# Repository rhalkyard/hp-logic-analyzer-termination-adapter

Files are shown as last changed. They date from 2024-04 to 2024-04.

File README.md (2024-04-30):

# Termination Adapter for HP Logic Analyzers

The PCB in this repo is a quick and dirty clone of the HP 01650-63203
termination adapter, used for direct connection of a 40-pin pod cable to a
dedicated test port, providing a passive termination network to minimise loading
on the device under test. By adding a cheap set of hookup leads and
minigrabbers, it can also serve as a DIY replacement for the probe pods that are
so frequently missing from analzyers that crop up on the used market.

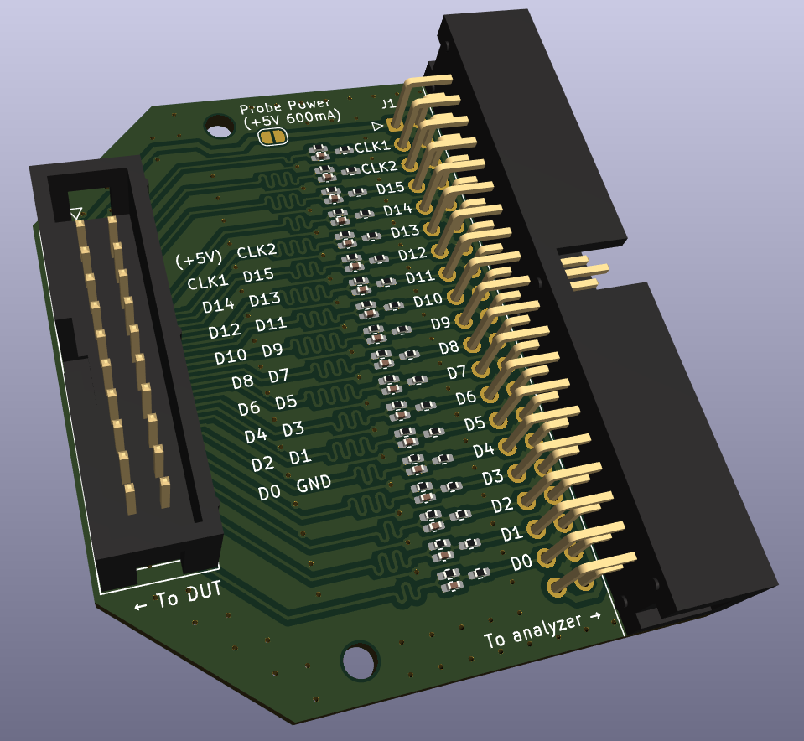
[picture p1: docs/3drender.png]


## Termination network

Per HP application note [AP1244 "Minimizing Intrusion Effects when Probing with
a Logic Analyzer"](docs/5962-8620E_AP1244-1_Minimizing_Intrusion_Effects_When_Probing_With_a_Logic_Analyzer_Jul95),
each probe must be terminated with a series RC network as below (from Figure 1):

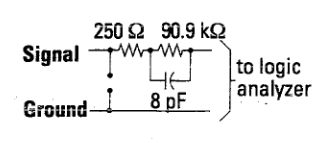
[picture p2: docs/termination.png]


HP sold arrays of this termination network (1810-1278 for 9 networks in a DIP
package, 1810-1588 for 5 networks in a SIP package). Naturally these are either
NLA or not available for purchase by mere mortals, but it's easy enough to
implement it in discrete components.

## Pinouts

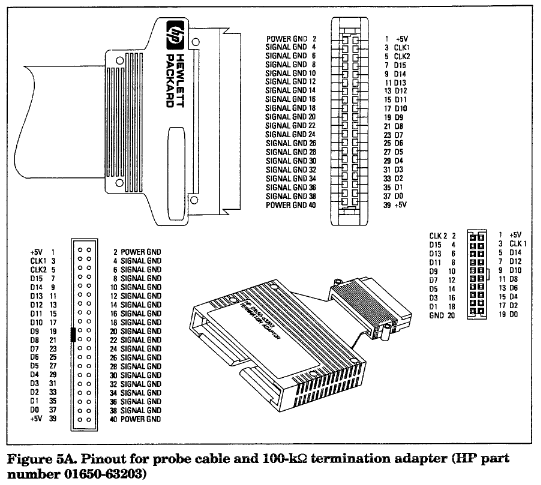
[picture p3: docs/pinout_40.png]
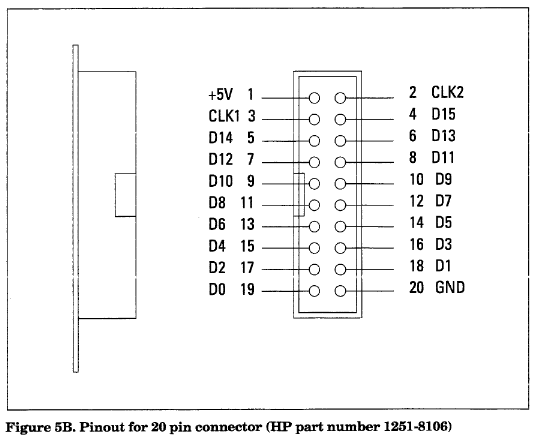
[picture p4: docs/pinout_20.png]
 

## Power

The logic analyzer supplies +5V at 600mA to each pod connector on pins 1 and 39
of the 40-pin connector. The 01650-63203 termination adatper brings this supply
out to pin 1 of the 20-pin connector. Per HP's documentation, this is intended
solely for powering active probe hardware, and must be a no-connect on the
device under test.

For safety, on this adapter, the +5V supply is broken by a solder jumper that
must be closed in order to supply +5V to the 20 pin connector.

## BOM and assembly

Each adapter requires the following

| Quantity | Component |
|---|---|
| 18 | Capacitor, 8pF, 0402 footprint |
| 18 | Resistor, 250 ohm 1%, 0402 footprint |
| 18 | Resistor, 90.9K 1%, 0402 footprint |
| 1 | Keyed 0.1" PCB header, 2x20 pin, right angle |
| 1 | Keyed 0.1" PCB header, 2x10 pin, vertical |
| 1 (optional) | 20 pin IDC ribbon cable, length to taste, female connectors |

Conveniently, JLCPCB's minimum order quantity of 5 is exactly the number of pods
required for my 1652B analyzer. I ordered a set of 5 boards with SMD components
preassembled for approximately 25 USD.

The original 01650-63203 adapters had an exposed section of flexible PCB,
terminated in a 20 pin IDC receptacle, designed to directly connect to a
board-mounted header on the DUT. This adapter substitutes this with a header - a
short length of ribbon cable can be used to connect to the DUT, or standard
Dupont leads can be connected to the pins for individual probes.

## (Lack of) Warranty

This project is presented on an as-is, 'works for me' basis. You are welcome to
build it, use it, adapt it to your own purposes, but all at your own risk.

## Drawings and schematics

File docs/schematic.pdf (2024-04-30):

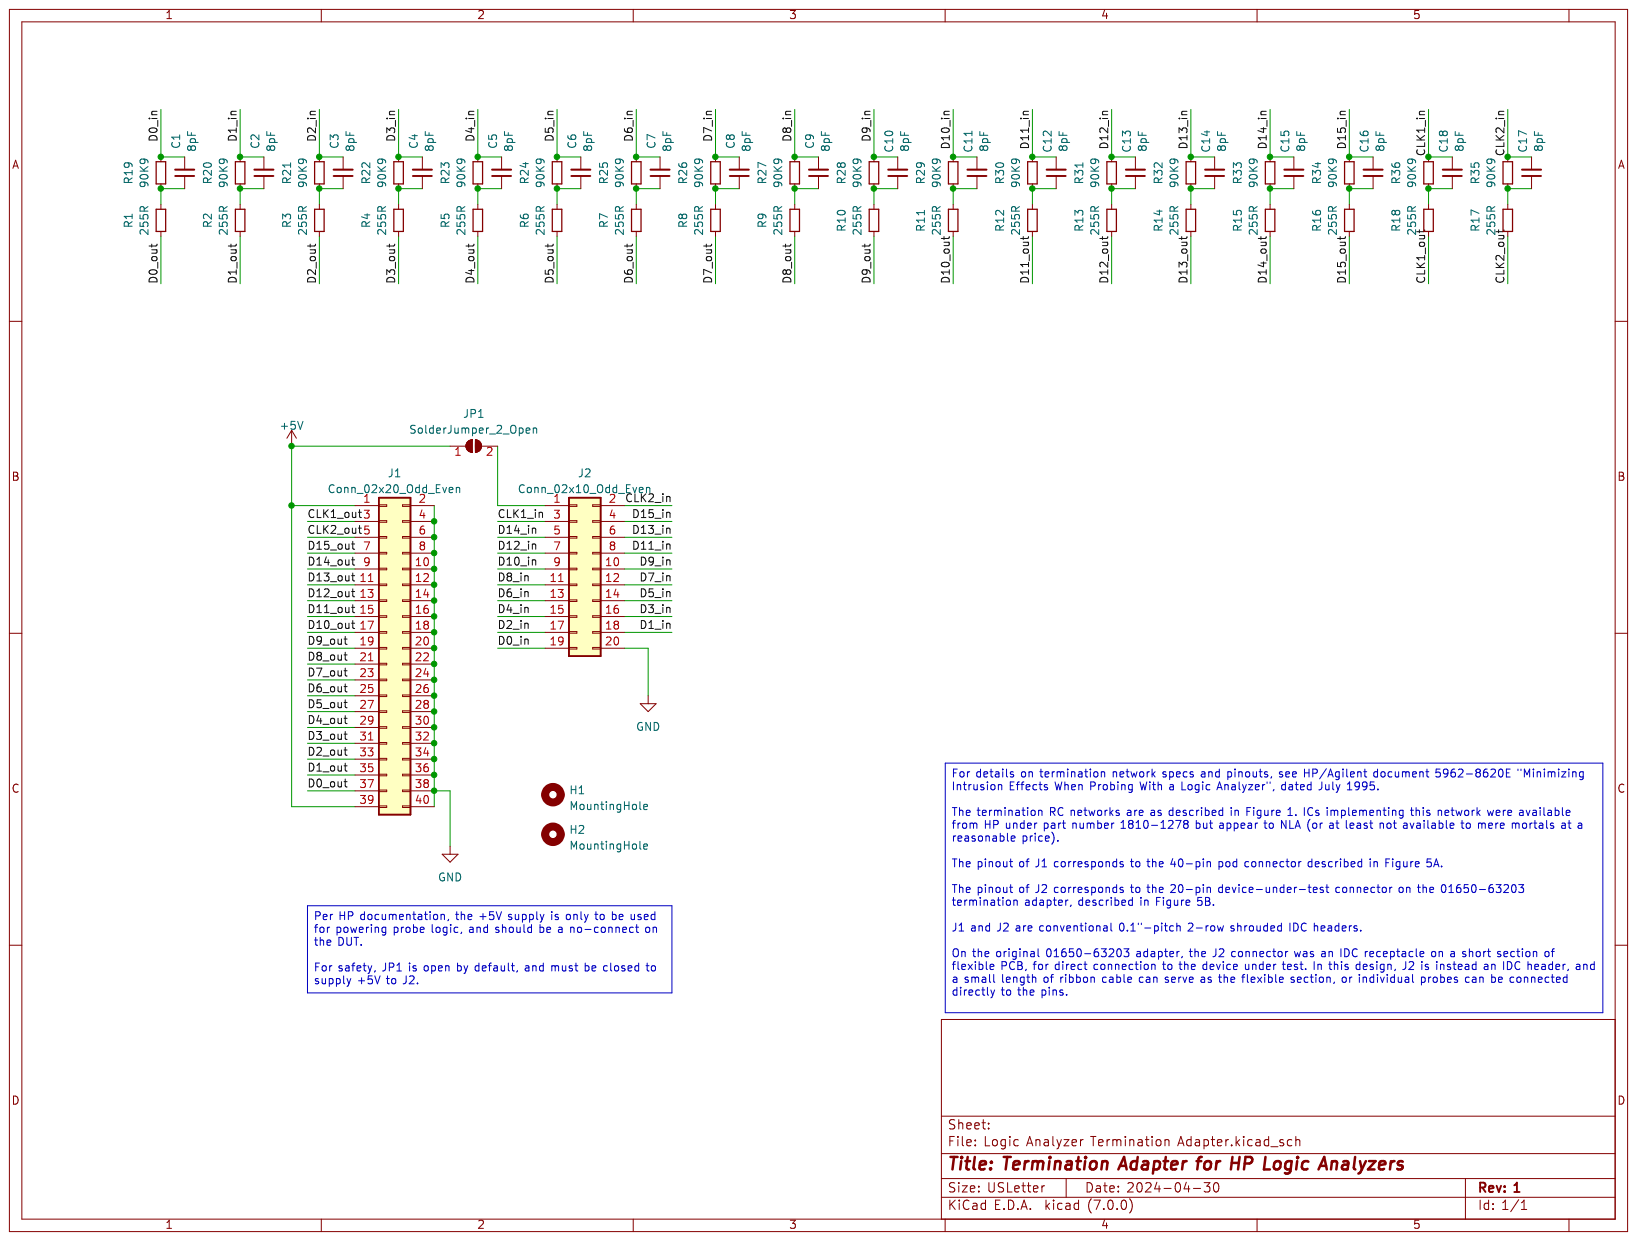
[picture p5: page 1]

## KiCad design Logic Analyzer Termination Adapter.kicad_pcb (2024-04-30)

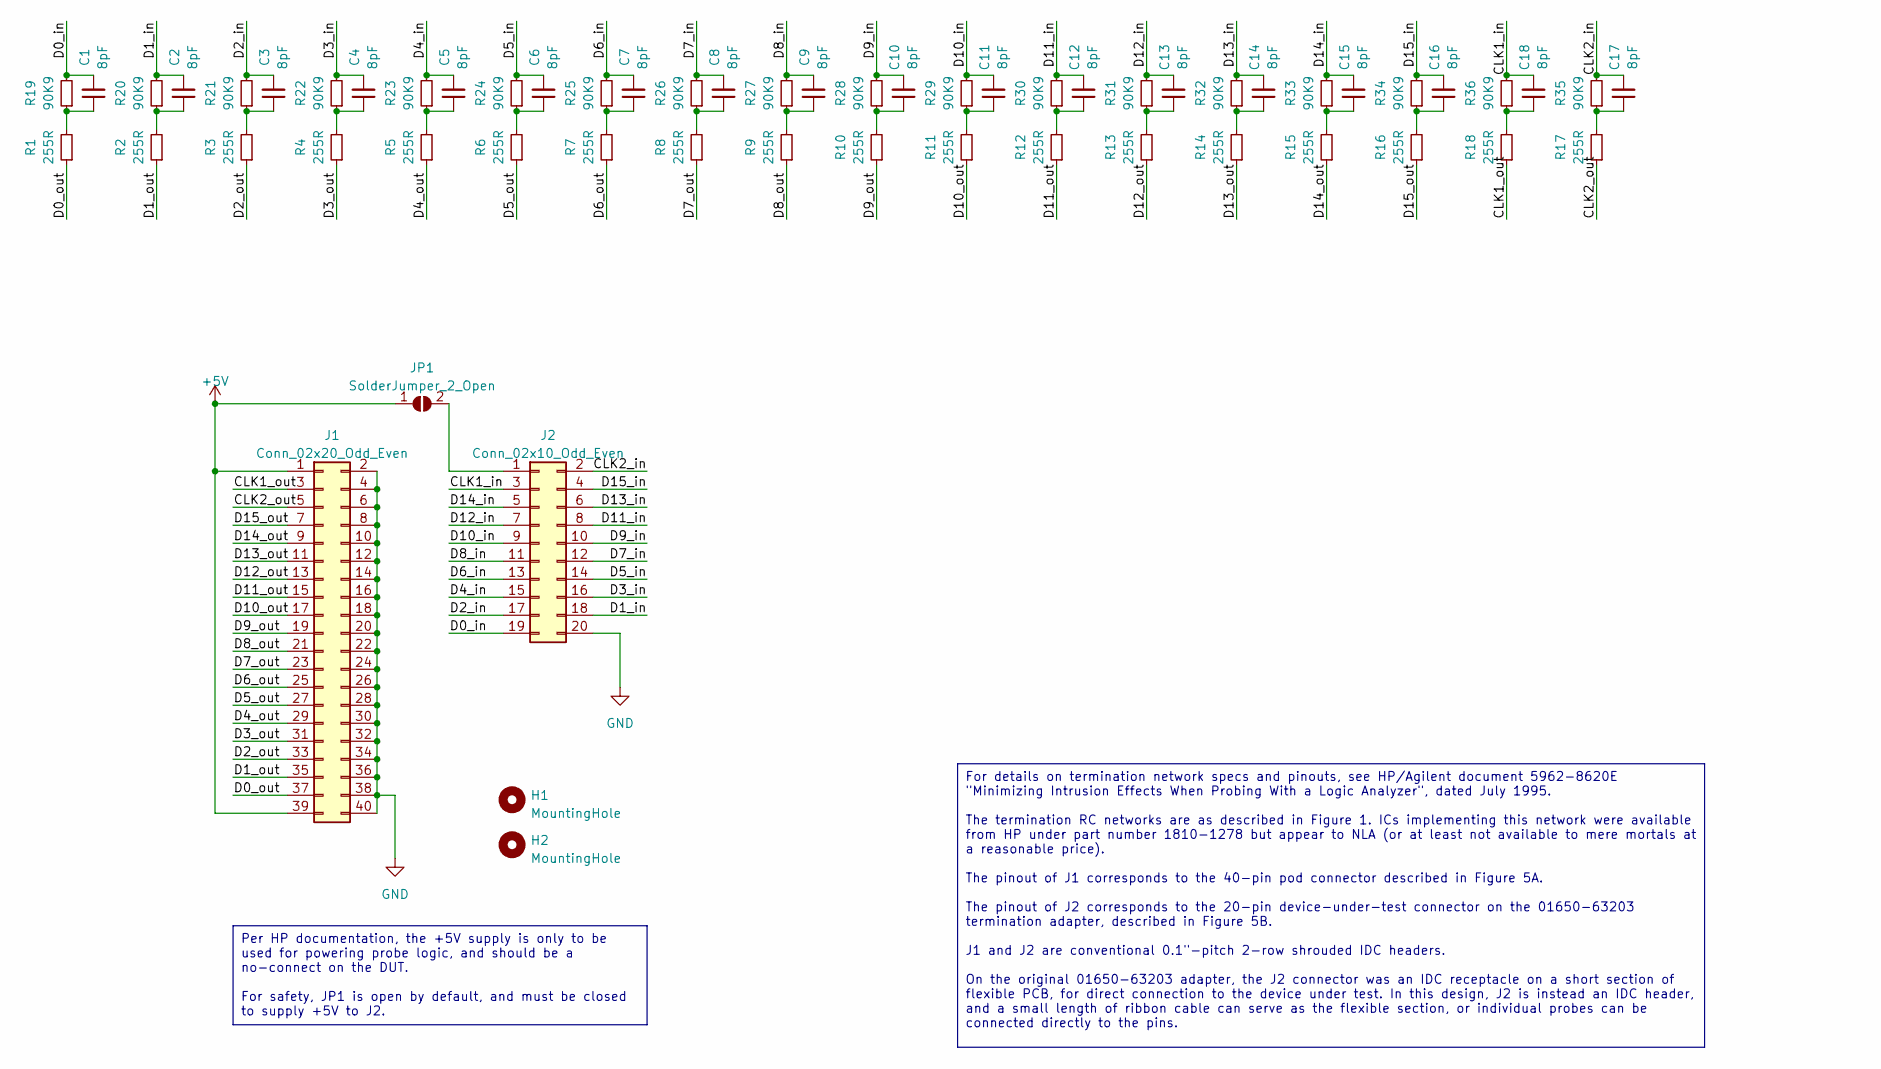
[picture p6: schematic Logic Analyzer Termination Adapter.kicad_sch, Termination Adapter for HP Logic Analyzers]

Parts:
C1, C2, C3, C4, C5, C6, C7, C8, C9, C10, C11, C12, C13, C14, C15, C16, C17, C18: 8pF; C_0402_1005Metric_Pad0.74x0.62mm_HandSolder; LCSC C880622
H1, H2: MountingHole; MountingHole_2.7mm_M2.5
J1: Conn_02x20_Odd_Even; IDC-Header_2x20_P2.54mm_Horizontal; MPN BHR-40-HUA
J2: Conn_02x10_Odd_Even; IDC-Header_2x10_P2.54mm_Vertical; MPN 302-S201
JP1: SolderJumper_2_Open; SolderJumper-2_P1.3mm_Open_RoundedPad1.0x1.5mm
R1, R2, R3, R4, R5, R6, R7, R8, R9, R10, R11, R12, R13, R14, R15, R16, R17, R18: 255R; R_0402_1005Metric_Pad0.72x0.64mm_HandSolder; LCSC C226375
R19, R20, R21, R22, R23, R24, R25, R26, R27, R28, R29, R30, R31, R32, R33, R34, R35, R36: 90K9; R_0402_1005Metric_Pad0.72x0.64mm_HandSolder; LCSC C2998102

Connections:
+5V: J1.1, J1.39, JP1.1 (A)
/CLK1_in: C18.2, J2.3, R36.2
/CLK1_out: J1.3, R18.1
/CLK2_in: C17.2, J2.2, R35.2
/CLK2_out: J1.5, R17.1
/D0_in: C1.2, J2.19, R19.2
/D0_out: J1.37, R1.1
/D1_in: C2.2, J2.18, R20.2
/D1_out: J1.35, R2.1
/D2_in: C3.2, J2.17, R21.2
/D2_out: J1.33, R3.1
/D3_in: C4.2, J2.16, R22.2
/D3_out: J1.31, R4.1
/D4_in: C5.2, J2.15, R23.2
/D4_out: J1.29, R5.1
/D5_in: C6.2, J2.14, R24.2
/D5_out: J1.27, R6.1
/D6_in: C7.2, J2.13, R25.2
/D6_out: J1.25, R7.1
/D7_in: C8.2, J2.12, R26.2
/D7_out: J1.23, R8.1
/D8_in: C9.2, J2.11, R27.2
/D8_out: J1.21, R9.1
/D9_in: C10.2, J2.10, R28.2
/D9_out: J1.19, R10.1
/D10_in: C11.2, J2.9, R29.2
/D10_out: J1.17, R11.1
/D11_in: C12.2, J2.8, R30.2
/D11_out: J1.15, R12.1
/D12_in: C13.2, J2.7, R31.2
/D12_out: J1.13, R13.1
/D13_in: C14.2, J2.6, R32.2
/D13_out: J1.11, R14.1
/D14_in: C15.2, J2.5, R33.2
/D14_out: J1.9, R15.1
/D15_in: C16.2, J2.4, R34.2
/D15_out: J1.7, R16.1
GND: J1.2, J1.4, J1.6, J1.8, J1.10, J1.12, J1.14, J1.16, J1.18, J1.20, J1.22, J1.24, J1.26, J1.28, J1.30, J1.32, J1.34, J1.36, J1.38, J1.40, J2.20
unnamed: C1.1, R1.2, R19.1
unnamed: C2.1, R2.2, R20.1
unnamed: C3.1, R3.2, R21.1
unnamed: C4.1, R4.2, R22.1
unnamed: C5.1, R5.2, R23.1
unnamed: C6.1, R6.2, R24.1
unnamed: C7.1, R7.2, R25.1
unnamed: C8.1, R8.2, R26.1
unnamed: C9.1, R9.2, R27.1
unnamed: C10.1, R10.2, R28.1
unnamed: C11.1, R11.2, R29.1
unnamed: C12.1, R12.2, R30.1
unnamed: C13.1, R13.2, R31.1
unnamed: C14.1, R14.2, R32.1
unnamed: C15.1, R15.2, R33.1
unnamed: C16.1, R16.2, R34.1
unnamed: C17.1, R17.2, R35.1
unnamed: C18.1, R18.2, R36.1
unnamed: J2.1, JP1.2 (B)

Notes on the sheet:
Per HP documentation, the +5V supply is only to be used for powering probe logic, and should be a no-connect on the DUT. For safety, JP1 is open by default, and must be closed to supply +5V to J2.
For details on termination network specs and pinouts, see HP/Agilent document 5962-8620E "Minimizing Intrusion Effects When Probing With a Logic Analyzer", dated July 1995. The termination RC networks are as described in Figure 1. ICs implementing this network were available from HP under part numb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

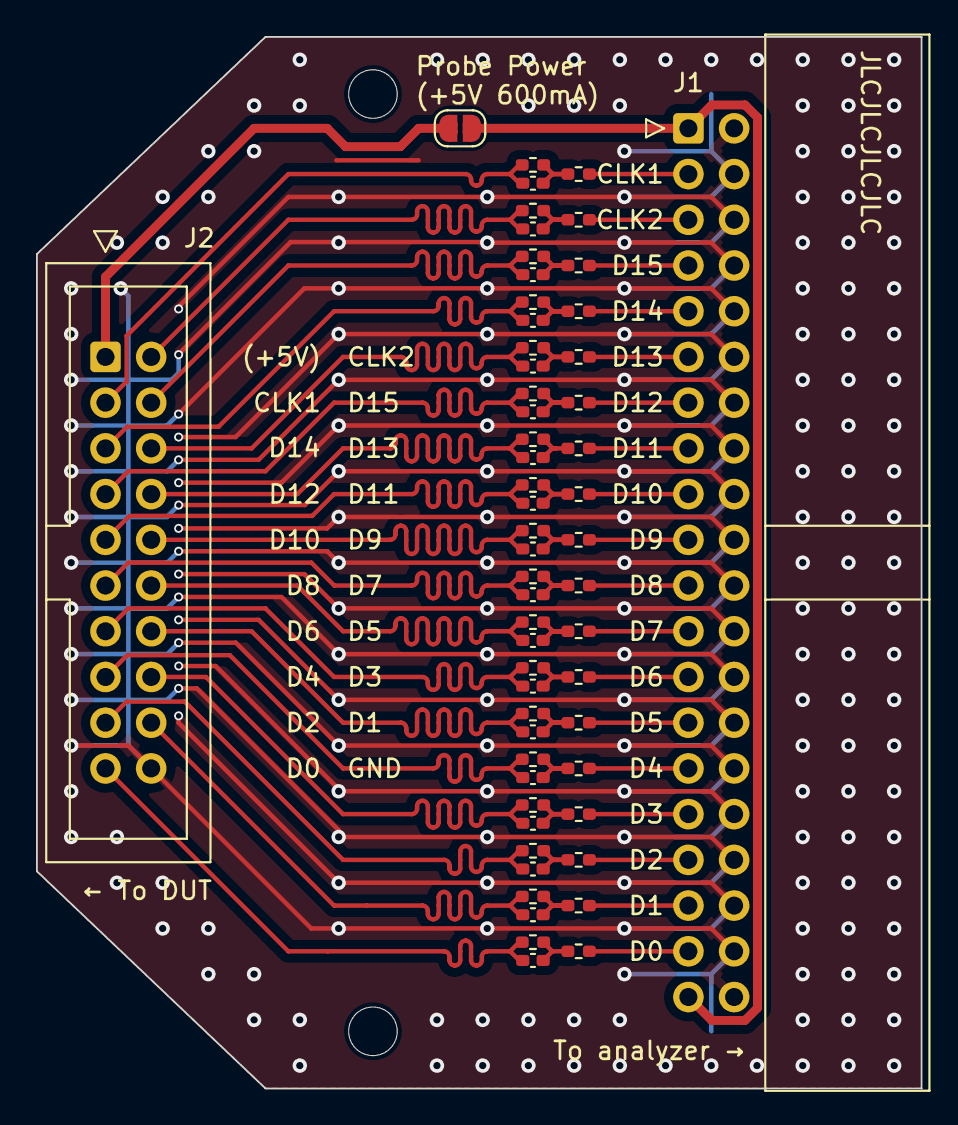
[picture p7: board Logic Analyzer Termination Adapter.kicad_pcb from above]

Board: 2 copper layers, 49.1 x 58.4 mm, 59 parts (0 on the bottom side), 57 nets.
